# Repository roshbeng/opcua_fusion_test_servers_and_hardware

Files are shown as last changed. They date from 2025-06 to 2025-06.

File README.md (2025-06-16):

# OPC UA Controlled Cobot and Conveyor System

This project features a 3D-printable 6-axis collaborative robot (Cobot) and a conveyor belt system, both designed to be controlled remotely via OPC UA servers running on Raspberry Pi. The system is a complete mechatronics project, including 3D CAD models, electronic circuit diagrams, and Python control scripts.

> **Note:** This project is designed to be tested with the OPC UA Fusion application available at [roshbeng/opcua_fusion](https://github.com/roshbeng/opcua_fusion.git). This client provides a user interface to connect to the servers and execute the defined methods.

## Features

*   **Remote Control:** Utilizes the OPC UA protocol for robust and standardized industrial communication.
*   **Raspberry Pi Based:** The control logic runs on Raspberry Pi, leveraging its GPIO capabilities to drive servo motors.
*   **Complete Design Files:** Includes comprehensive CAD models in various formats (`.f3d`, `.step`, `.ipt`, `.pdf`) for both the cobot and the conveyor.
*   **Asynchronous Operation:** Built with Python's `asyncio` and the `asyncua` library for efficient, non-blocking server operation.
*   **Hardware Control:** Directly interfaces with servo motors for physical movement and includes a physical shutdown button for safety.
*   **Modular:** The cobot and conveyor operate as separate, independent systems, each with its own OPC UA server.

## Project Structure

```
.
├── requirements.txt
├── CAD models
│   ├── cobot_model
│   │   ├── cobot individual components in step format
│   │   └── cobot_model_v1_inventor
│   └── conveyor_model
│       ├── conveyor individual components in step format
│       └── conveyor_model_v1
├── opcuaprojectcobot
│   ├── cobot_model_3d_cad_design.png
│   ├── the_electronic_circuit_of_the_cobot_model.PNG
│   ├── opcua_cobot_server.py
│   ├── initialze.py
│   ├── robo_arm_without_opc.py
│   └── shutdownbutton.py
└── opcuaprojectconveyor
    ├── conveyor_model_3d_cad_design.png
    ├── the_electronic_circuit_of_the_conveyor_model.PNG
    ├── opcua_conveyor_server.py
    └── shutdownbutton.py
```

## 1. Collaborative Robot (Cobot)

The cobot is a 6-axis robotic arm designed for pick-and-place operations. It is controlled by five servo motors for its joints and one for the gripper.

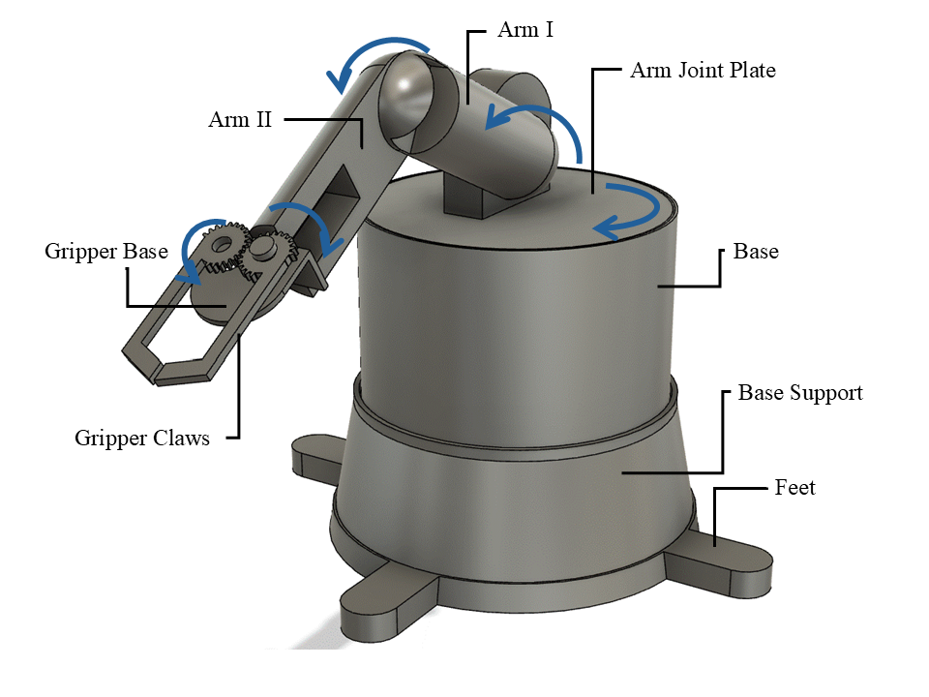
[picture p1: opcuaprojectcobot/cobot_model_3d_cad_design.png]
Cobot 3D Model


### Cobot Electronics

The cobot is controlled by a Raspberry Pi connected to six servo motors and a physical shutdown button.

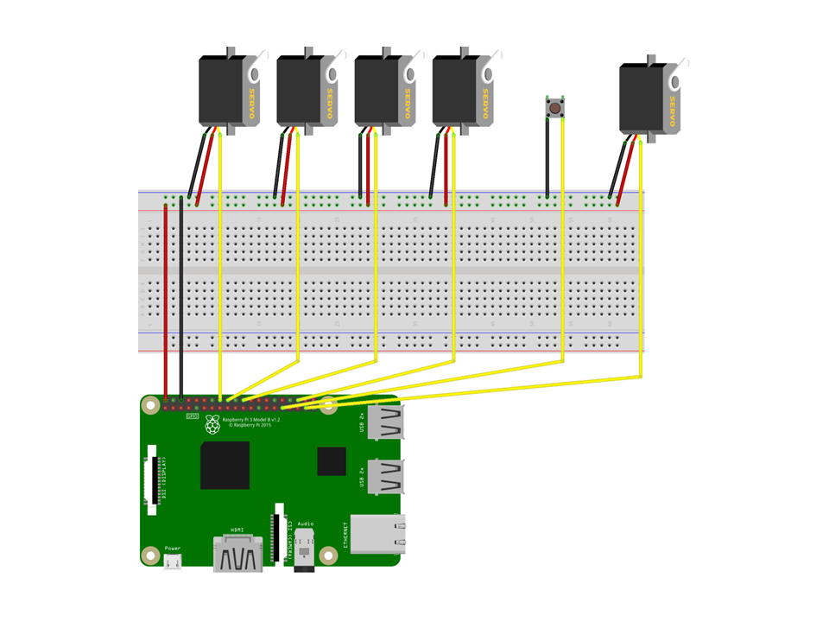
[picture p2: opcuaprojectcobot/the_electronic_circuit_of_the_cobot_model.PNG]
Cobot Circuit Diagram


### Cobot OPC UA Server (`opcua_cobot_server.py`)

This script creates an OPC UA server on a Raspberry Pi to expose control methods for the cobot.

*   **Endpoint:** `opc.tcp://192.168.1.3:4840/cobot_arm`
*   **GPIO Pins Used:**
    *   Servos: `16`, `25`, `23`, `24`, `26`
    *   Shutdown Button: `6`
*   **OPC UA Methods:**
    *   `move_arm(command_bool)`: Executes a pre-programmed sequence of movements. Returns `True` on completion.
    *   `reference_cobot()`: Moves the cobot to a home/reference position. Returns `True`.
    *   `stop_cobot()`: Stops all servos and initiates a system shutdown of the Raspberry Pi.
*   **OPC UA Variables & Properties:**
    *   `claw_position`: A variable to hold the gripper's position (not fully implemented in the provided script).
    *   `server_timestamp`: A variable that updates every second with the current server time.
    *   `Manufacturer`: "HomeBuiltCobot"
    *   `Version`: "1.0"

## 2. Conveyor System

A simple conveyor system designed to transport parts. It is driven by a single continuous rotation servo motor.

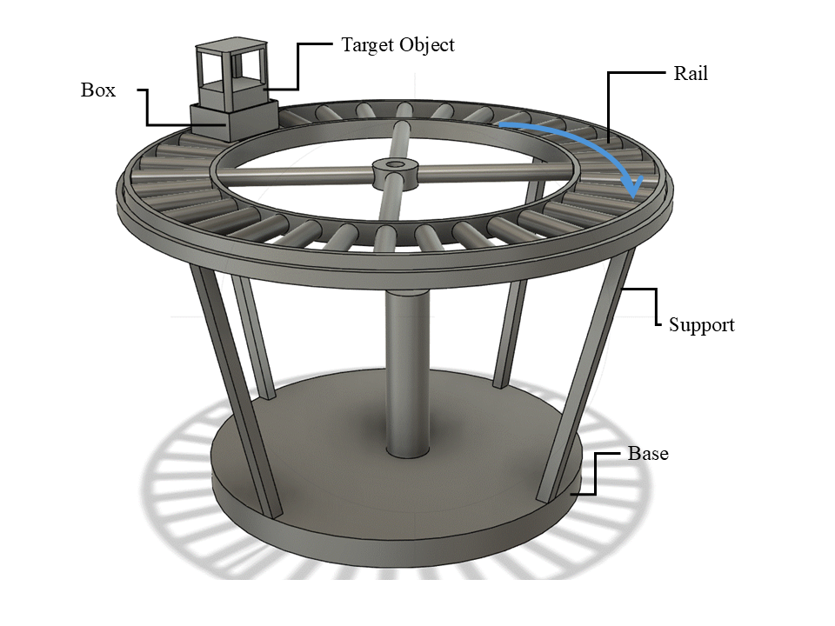
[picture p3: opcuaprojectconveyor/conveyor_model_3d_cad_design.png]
Conveyor 3D Model


### Conveyor Electronics

The conveyor is controlled by a separate Raspberry Pi, connected to one servo and a shutdown button.

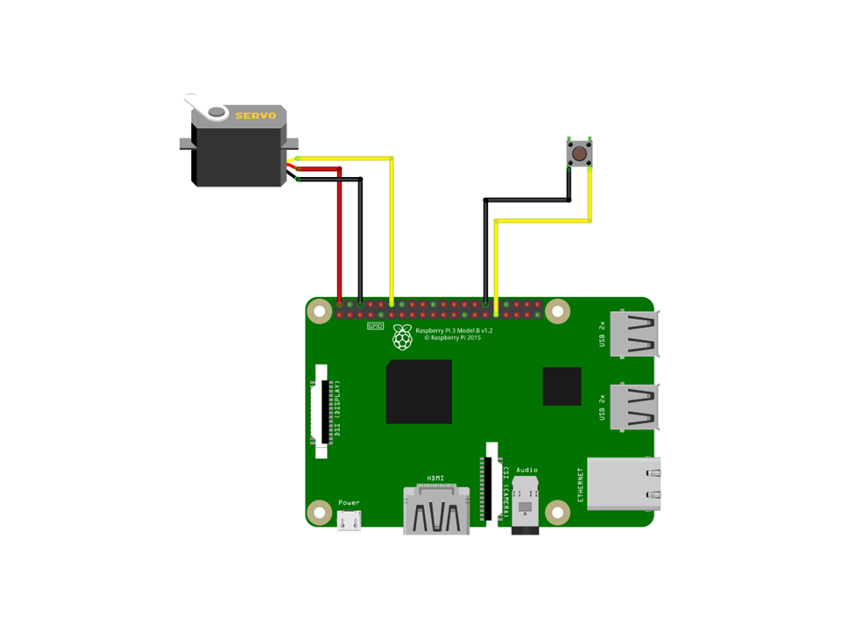
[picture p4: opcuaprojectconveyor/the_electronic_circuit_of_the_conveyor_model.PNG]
Conveyor Circuit Diagram


### Conveyor OPC UA Server (`opcua_conveyor_server.py`)

This script creates an OPC UA server to control the conveyor motor.

*   **Endpoint:** `opc.tcp://192.168.1.2:4840/conveyor`
*   **GPIO Pins Used:**
    *   Servo: `18`
    *   Shutdown Button: `6`
*   **OPC UA Methods:**
    *   `initialize()`: Moves the conveyor to an initial/home position. Returns `True`.
    *   `move_and_supply()`: Runs the conveyor motor to transport items. Returns `True`.
*   **OPC UA Variables & Properties:**
    *   `server_timestamp`: A variable that updates every second with the current server time.
    *   `Manufacturer`: "HomeBuiltConveyor"
    *   `Version`: "1.0"

## 3. CAD Models

The `CAD models` directory contains all the source files for 3D printing and assembly.
*   **Fusion 360 (`.f3d`):** The primary source files for the assemblies.
*   **STEP (`.step`):** A neutral format for use in any CAD software. Individual components are also provided in this format.
*   **Inventor (`.ipt`, `.iam`):** Native files for Autodesk Inventor.
*   **PDF (`.pdf`):** 2D technical drawings of the components.

## Getting Started

### Prerequisites

*   **Hardware:**
    *   2 x Raspberry Pi (3B+ or newer recommended)
    *   ~6 x Servo Motors (e.g., MG996R or similar)
    *   2 x Push Buttons
    *   Breadboards, jumper wires, and an appropriate power supply for the servos.
    *   Ethernet cables and a network switch for direct connection (optional but recommended).
*   **Software:**
    *   Python 3.7+
    *   Git

### Installation & Setup

1.  **Clone the repository:**
    ```bash
    git clone https://github.com/roshbeng/opcua_fusion_test_servers_and_hardware.git
    cd opcua_fusion_test_servers_and_hardware
    ```

2.  **Install Python dependencies:**
    ```bash
    pip install -r requirements.txt
    ```
    Note: `RPi.GPIO` can only be installed and used on a Raspberry Pi.

3.  **Hardware Wiring:**
    *   **For the Cobot Pi:** Connect the servo signal wires to GPIO pins 16, 25, 23, 24, 26. Connect the shutdown button to GPIO 6.
    *   **For the Conveyor Pi:** Connect the servo signal wire to GPIO pin 18. Connect the shutdown button to GPIO 6.
    *   Ensure all servos and the Raspberry Pis have a common ground (GND). Power the servos with a separate, adequate power supply.

4.  **Network Configuration:**
    The scripts use hardcoded IP addresses: `192.168.1.3` for the cobot and `192.168.1.2` for the conveyor. You must either:
    *   **Option A (Recommended):** Set up a direct Ethernet connection to your laptop by creating a network bridge. See the section below.
    *   **Option B:** Assign these static IPs to your Raspberry Pis on your existing network.
    *   **Option C:** Modify the `endpoint` URL in each server script (`opcua_cobot_server.py` and `opcua_conveyor_server.py`) to match the actual IP addresses of your devices.

### 🔌 Connecting Hardware Directly via Ethernet (Network Bridge)

To connect the Raspberry Pi-based hardware directly to the laptop running the client application without an external router, you can create a network bridge.

#### Network Topology

```
(Internet) --- Wi-Fi ---> [ Laptop (Running Client) ] --- Ethernet ---> [ Switch ] --- Ethernet ---> [ Pi 1: Conveyor (192.168.1.2) ]
                                                                             |
                                                                              --- Ethernet ---> [ Pi 2: Cobot (192.168.1.3) ]
```

#### Laptop Setup Guide

Your laptop must have a static IP address on the same network as the hardware. We will use the `192.168.1.x` subnet.

**On Windows:**

1.  Open Network Connections: Press `Win + R`, type `ncpa.cpl`, and press Enter.
2.  **Set Static IP on Ethernet Port**: Right-click your **Ethernet** adapter > **Properties** > **Internet Protocol Version 4 (TCP/IPv4)** > **Properties**. Select "Use the following IP address" and enter:
    -   IP address: `192.168.1.1`
    -   Subnet mask: `255.255.255.0`
3.  **Share Wi-Fi Connection**: Right-click your **Wi-Fi** adapter > **Properties** > **Sharing** tab. Check the box "Allow other network users to connect..." and select your **Ethernet** adapter from the dropdown.

**On macOS:**

1.  Open **System Settings** > **Network**.
2.  **Set Static IP on Ethernet Port**: Select your **Ethernet** adapter > **Details...** > **TCP/IP**. Set "Configure IPv4" to **Manually** and enter:
    -   IP Address: `192.168.1.1`
    -   Subnet Mask: `255.255.255.0`
3.  **Share Wi-Fi Connection**: Go to **System Settings** > **General** > **Sharing**. Turn on **Internet Sharing**. Configure it to share from **Wi-Fi** to computers using your **Ethernet** adapter.

### Running the Servers

1.  **On the Cobot Raspberry Pi**, run:
    ```bash
    python opcuaprojectcobot/opcua_cobot_server.py
    ```

2.  **On the Conveyor Raspberry Pi**, run:
    ```bash
    python opcuaprojectconveyor/opcua_conveyor_server.py
    ```

You should see a message indicating that the OPC UA server has started on each device.

### Interacting with the System

Use an OPC UA client to connect to the servers and control the hardware. The [opcua_fusion](https://github.com/roshbeng/opcua_fusion.git) project is recommended.

1.  Start the client application on your laptop.
2.  Connect to the Cobot server endpoint: `opc.tcp://192.168.1.3:4840/cobot_arm`
3.  Connect to the Conveyor server endpoint: `opc.tcp://192.168.1.2:4840/conveyor`
4.  Once connected, you can browse the OPC UA objects and call the methods (e.g., `move_arm`, `initialize`) to operate the system.

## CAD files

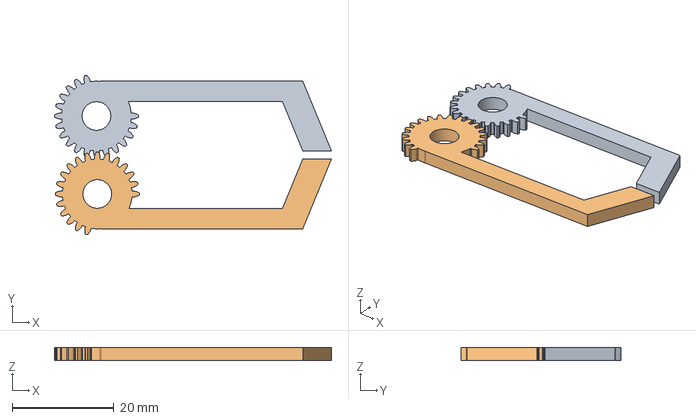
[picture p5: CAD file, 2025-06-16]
CAD models/cobot_model/cobot individual components in step format/GRIPPER CLAW v2.step
54.5 x 31.4 x 2.64 mm

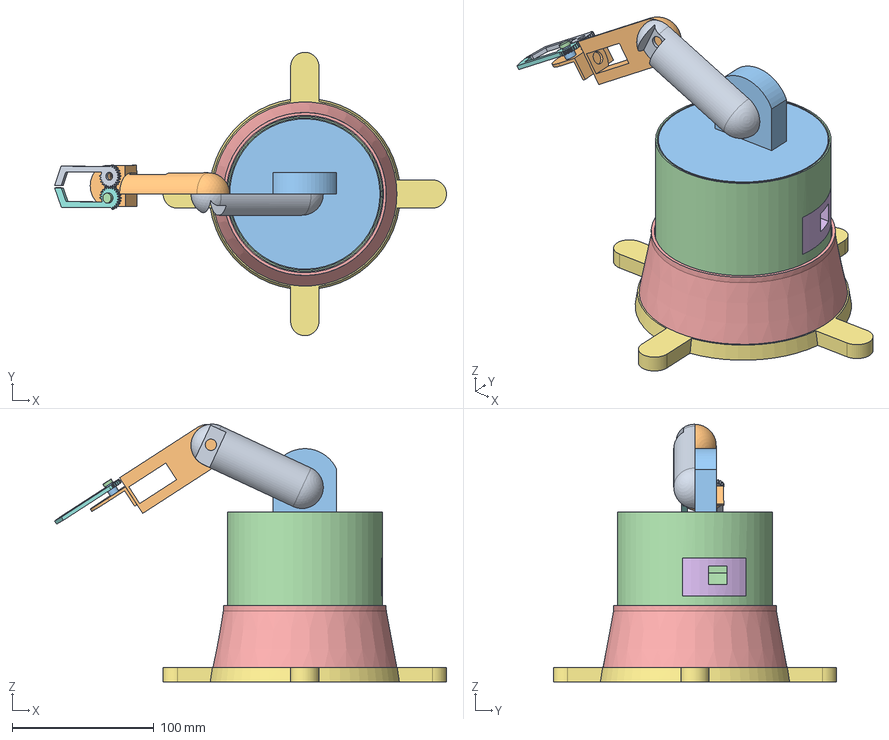
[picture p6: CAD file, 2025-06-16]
CAD models/cobot_model/cobot_model_v1.step
276.7 x 200.0 x 181.9 mm
arm1
arm2
shoulder
base1 (1)
base2
base1
base_support
gripper_assembly

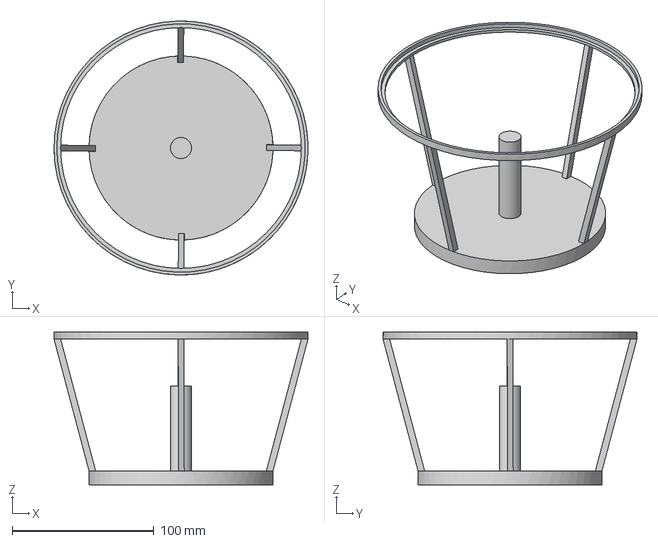
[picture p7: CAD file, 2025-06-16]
CAD models/conveyor_model/conveyor individual components in step format/base_and_support v3.step
179.4 x 179.4 x 108.0 mm

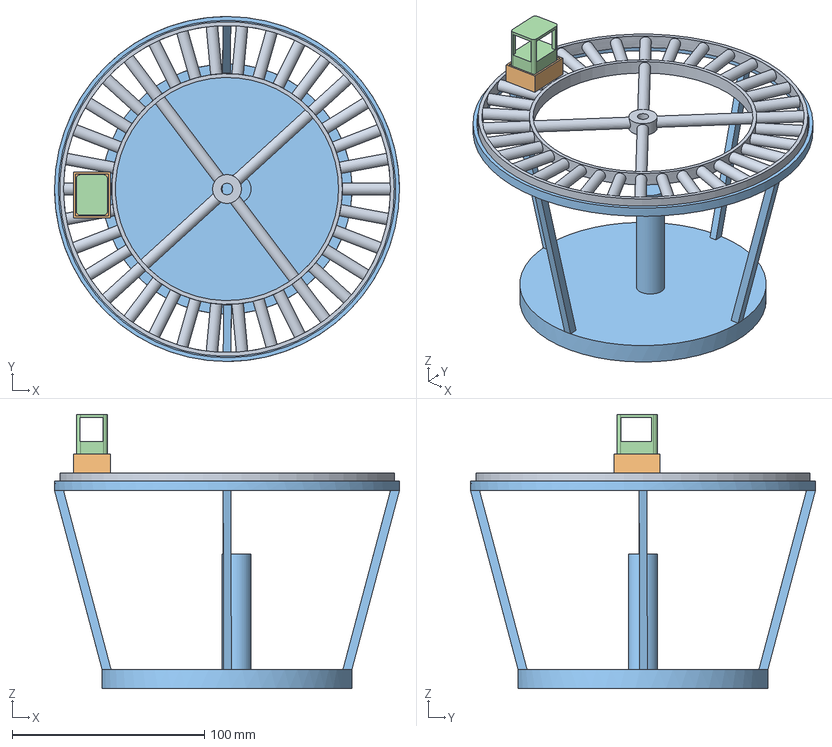
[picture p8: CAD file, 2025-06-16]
CAD models/conveyor_model/conveyor_model_v1.step
179.4 x 179.4 x 142.5 mm
rail
support

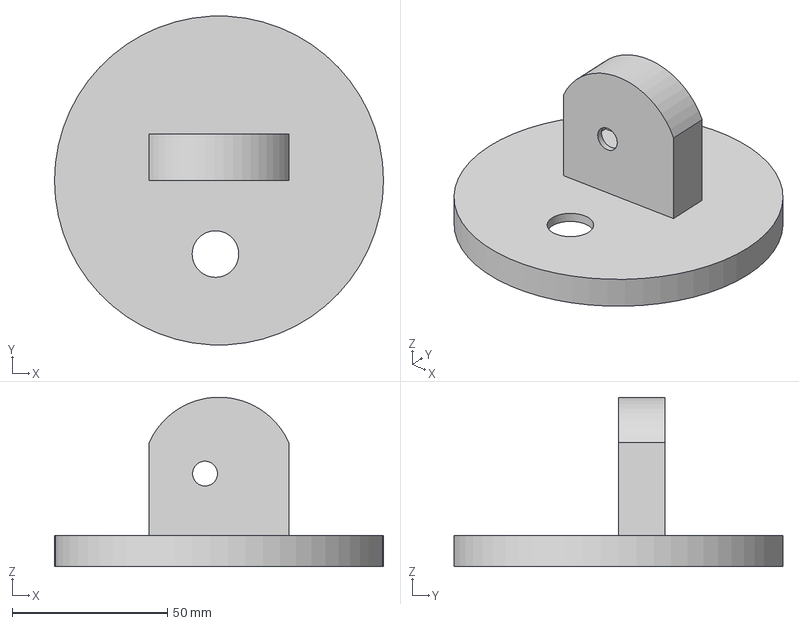
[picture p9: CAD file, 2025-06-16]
CAD models/cobot_model/cobot individual components in step format/ARM JOINT PLATE v3.step
106.0 x 105.8 x 54.6 mm

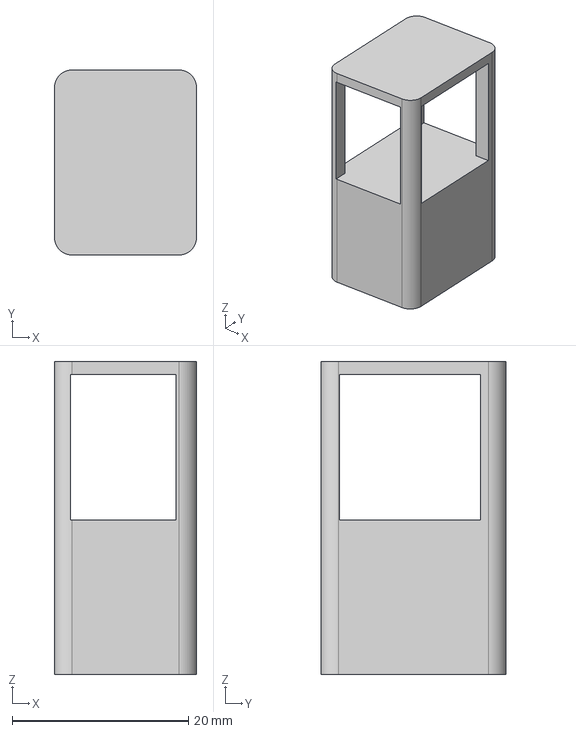
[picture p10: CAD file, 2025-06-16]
CAD models/conveyor_model/conveyor individual components in step format/pick v2.step
16.1 x 21.0 x 35.5 mm

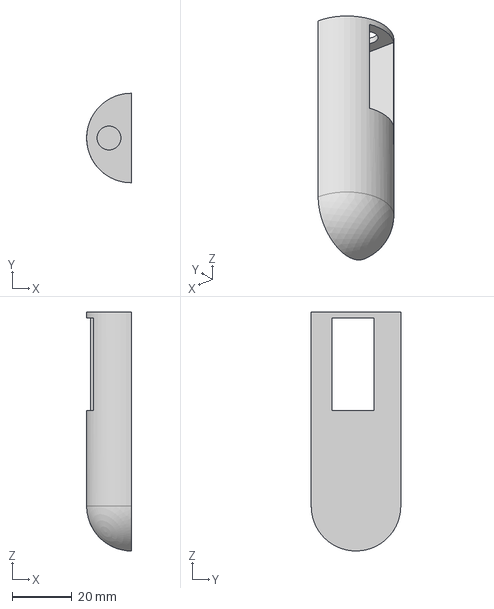
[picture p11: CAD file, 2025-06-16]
CAD models/cobot_model/cobot individual components in step format/ARM II v7.step
15.0 x 30.0 x 80.0 mm

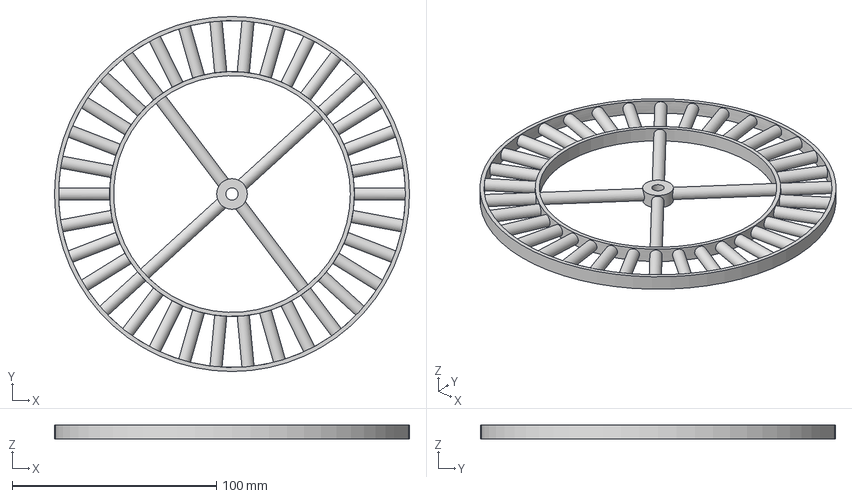
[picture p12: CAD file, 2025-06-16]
CAD models/conveyor_model/conveyor individual components in step format/rail v2.step
174.0 x 174.0 x 7.00 mm

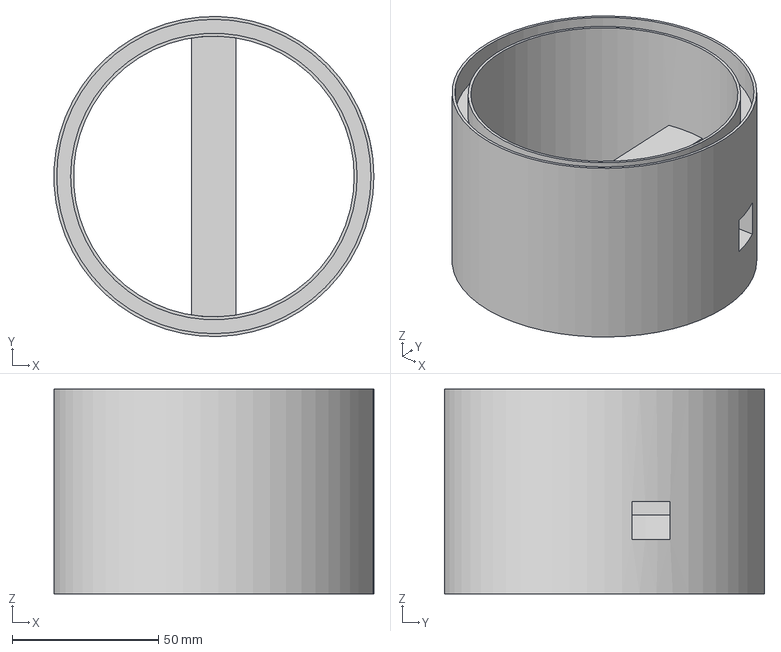
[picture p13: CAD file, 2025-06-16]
CAD models/cobot_model/cobot individual components in step format/BASE v4.step
109.4 x 109.5 x 70.0 mm
base1 (1)
base1

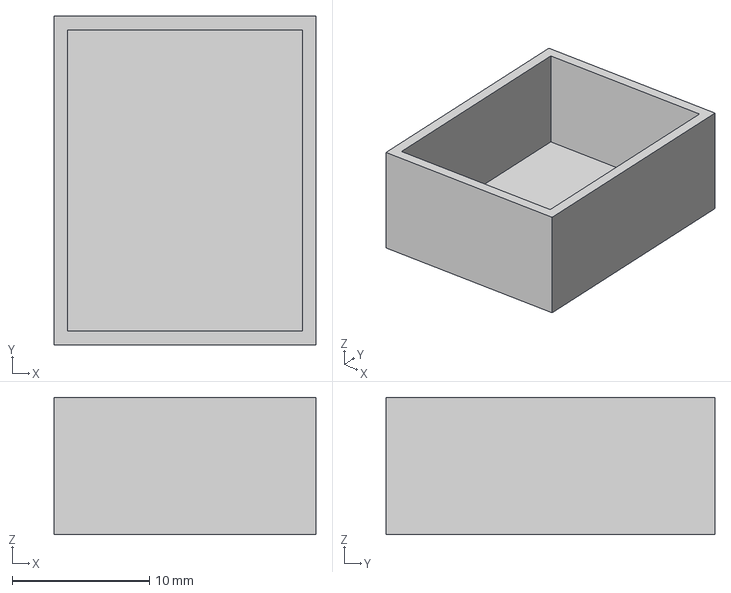
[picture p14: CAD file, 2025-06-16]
CAD models/conveyor_model/conveyor individual components in step format/box v2.step
19.1 x 24.0 x 10.0 mm

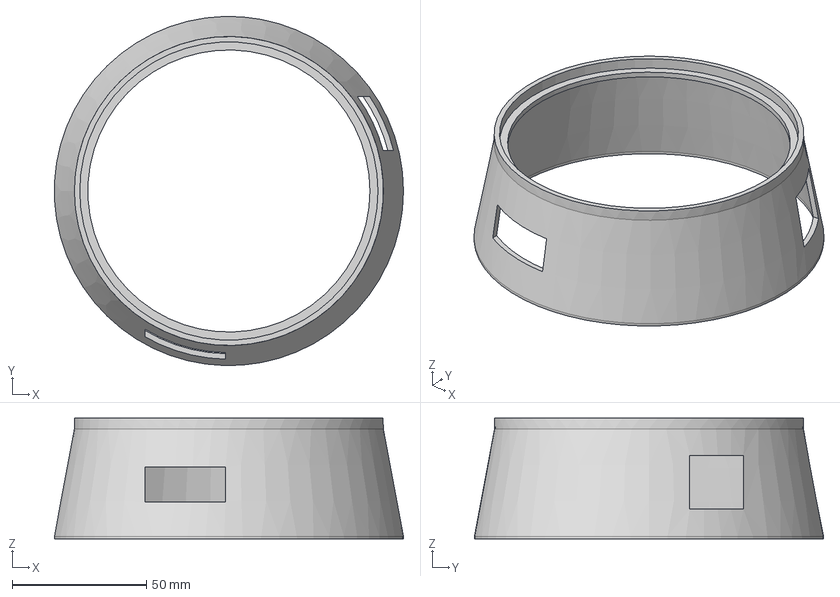
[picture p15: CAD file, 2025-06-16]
CAD models/cobot_model/cobot individual components in step format/BASE SUPPORT v8.step
129.9 x 130.0 x 45.0 mm

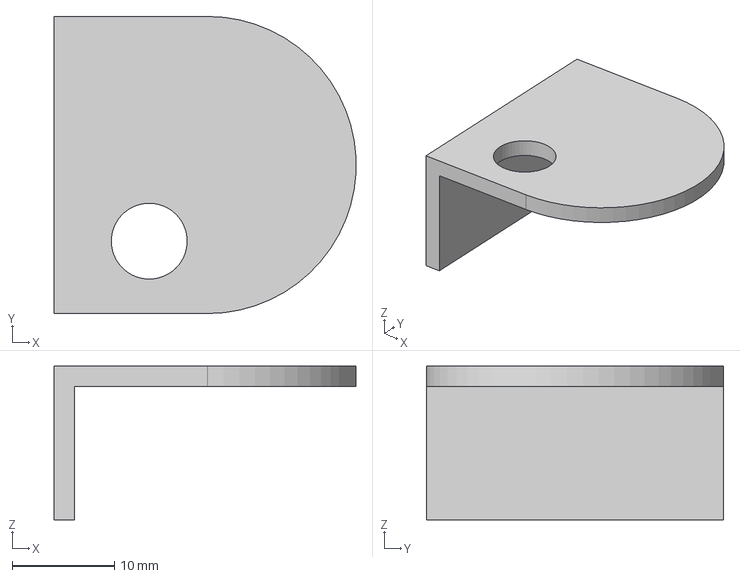
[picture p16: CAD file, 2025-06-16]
CAD models/cobot_model/cobot individual components in step format/GRIPPER BASE v2.step
29.5 x 29.0 x 15.0 mm

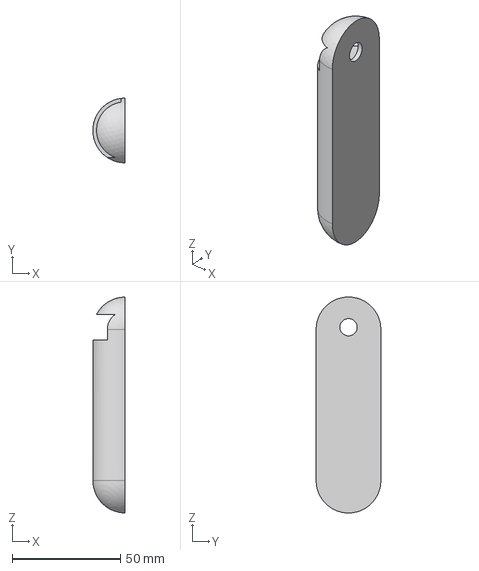
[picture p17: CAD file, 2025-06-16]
CAD models/cobot_model/cobot individual components in step format/ARM I v5.step
15.0 x 30.0 x 100.0 mm

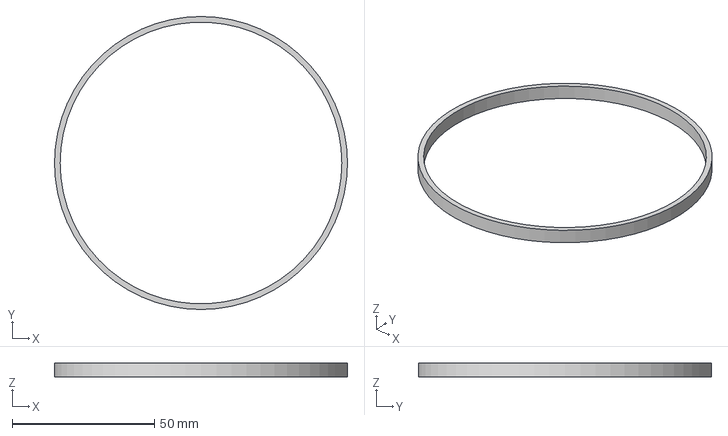
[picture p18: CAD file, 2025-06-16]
CAD models/cobot_model/cobot individual components in step format/ring v3.step
103.0 x 103.0 x 5.00 mm

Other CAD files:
CAD models/cobot_model/cobot individual components in step format/GRIPPER SUPPORTS I, II & III v5.step
CAD models/cobot_model/cobot individual components in step format/COBOT'S FOOT.step
CAD models/cobot_model/cobot_model_v1_inventor/Part16.ipt
CAD models/cobot_model/cobot_model_v1_inventor/arm1.ipt
CAD models/cobot_model/cobot_model_v1_inventor/arm2.ipt
CAD models/cobot_model/cobot_model_v1_inventor/base1 (1).ipt
CAD models/cobot_model/cobot_model_v1_inventor/base1.ipt
CAD models/cobot_model/cobot_model_v1_inventor/base2.ipt
CAD models/cobot_model/cobot_model_v1_inventor/base_support.ipt
CAD models/cobot_model/cobot_model_v1_inventor/gripper_assembly.iam
CAD models/cobot_model/cobot_model_v1_inventor/robotic_arm.iam
CAD models/cobot_model/cobot_model_v1_inventor/shoulder.ipt
CAD models/conveyor_model/conveyor_model_v1.f3d
CAD models/conveyor_model/conveyor_model_v1/box.ipt
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

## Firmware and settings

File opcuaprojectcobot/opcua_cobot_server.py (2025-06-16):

import asyncio
from asyncua import ua, uamethod, Server
from datetime import datetime, timezone
import re, sys, os
import RPi.GPIO as GPIO
from time import sleep

pwm_objects = {}

def get_or_create_pwm(pin, frequency=50):
    if pin not in pwm_objects:
        GPIO.setup(pin, GPIO.OUT)
        new_pwm = GPIO.PWM(pin, frequency)
        new_pwm.start(0)
        pwm_objects[pin] = new_pwm 
    return pwm_objects[pin]


def stop_all_servos():
    for pwm_obj in pwm_objects.values():
        pwm_obj.stop()
    pwm_objects.clear()


def cleanup_gpio():
    GPIO.cleanup()
    print("GPIO cleanup completed.")

BUTTON_PIN = 6

async def monitor_button():

    while True:
        button_state = GPIO.input(BUTTON_PIN)
        if button_state == 0:
            print("Physical button pressed - shutting down system...")
            stop_all_servos()
            cleanup_gpio()
            os.system("sudo shutdown -h now")
        await asyncio.sleep(0.1)


@uamethod
async def move_arm(parent, command_bool):
    try:
        GPIO.setmode(GPIO.BCM)

        pwm16 = get_or_create_pwm(16)
        pwm25 = get_or_create_pwm(25)
        pwm23 = get_or_create_pwm(23)
        pwm24 = get_or_create_pwm(24)
        pwm26 = get_or_create_pwm(26)

        if command_bool:
            print("Moving arm...")
            pwm25.ChangeDutyCycle(8.5)
            await asyncio.sleep(1)
            pwm26.ChangeDutyCycle(12.5)
            await asyncio.sleep(1)
            pwm23.ChangeDutyCycle(3.5)
            await asyncio.sleep(1)
            pwm23.ChangeDutyCycle(6)
            await asyncio.sleep(1)
            pwm16.ChangeDutyCycle(12.5)
            await asyncio.sleep(1)
            pwm24.ChangeDutyCycle(12.5)
            await asyncio.sleep(1)
            pwm23.ChangeDutyCycle(4)
            await asyncio.sleep(1)
            pwm26.ChangeDutyCycle(10)
            await asyncio.sleep(1)
            pwm25.ChangeDutyCycle(10.5)
            await asyncio.sleep(1)
            pwm26.ChangeDutyCycle(12.5)
            await asyncio.sleep(1)
            pwm23.ChangeDutyCycle(6)
            await asyncio.sleep(1)
            pwm25.ChangeDutyCycle(9)
            await asyncio.sleep(1)
            pwm16.ChangeDutyCycle(3.5)
            await asyncio.sleep(1)
            pwm25.ChangeDutyCycle(11)
            await asyncio.sleep(1)
            pwm23.ChangeDutyCycle(4)
            await asyncio.sleep(1)
            pwm26.ChangeDutyCycle(10)
            await asyncio.sleep(1)
            pwm25.ChangeDutyCycle(9.5)
            await asyncio.sleep(1)
            pwm26.ChangeDutyCycle(12.5)
            await asyncio.sleep(1)
            pwm23.ChangeDutyCycle(3.5)
            await asyncio.sleep(1)
            print("Arm movement completed.")

            print("Going to home position...")
            pwm16.ChangeDutyCycle(7)
            await asyncio.sleep(1)
            pwm25.ChangeDutyCycle(8)
            await asyncio.sleep(1)
            pwm26.ChangeDutyCycle(10)
            await asyncio.sleep(1)
            pwm23.ChangeDutyCycle(3.5)
            await asyncio.sleep(1)
            pwm24.ChangeDutyCycle(12.5)
            await asyncio.sleep(1)
            pwm26.ChangeDutyCycle(12.5)
            await asyncio.sleep(1)
            stop_all_servos()
        else:
            print("Stopping arm movement...")

    except Exception as e:
        print(f"Error during arm movement: {e}")
        cleanup_gpio()

    return True

@uamethod
async def reference_cobot(parent):
    try:
        print("Referencing Cobot...")
        pwm16 = get_or_create_pwm(16)
        pwm25 = get_or_create_pwm(25)
        pwm23 = get_or_create_pwm(23)
        pwm24 = get_or_create_pwm(24)
        pwm26 = get_or_create_pwm(26)

        pwm16.ChangeDutyCycle(7)
        await asyncio.sleep(1)
        pwm25.ChangeDutyCycle(8)
        await asyncio.sleep(1)
        pwm26.ChangeDutyCycle(10)
        await asyncio.sleep(1)
        pwm23.ChangeDutyCycle(3.5)
        await asyncio.sleep(1)
        pwm24.ChangeDutyCycle(12.5)
        await asyncio.sleep(1)
        pwm26.ChangeDutyCycle(12.5)
        await asyncio.sleep(1)

        print("Cobot referenced successfully.")
        stop_all_servos()

    except Exception as e:
        print(f"Error during referencing: {e}")
        cleanup_gpio()

    return True

@uamethod
async def stop_cobot(parent):
    print("Cobot stopping, and shutting down the system...")
    await asyncio.sleep(3)
    stop_all_servos()
    cleanup_gpio()
    os.system("sudo shutdown -h now")
    return True


async def generate_opc_model(server, namespace_id):
    cobot_interface = await server.nodes.objects.add_object(namespace_id, "cobot interface")

    claw_position = await cobot_interface.add_variable(namespace_id, "claw position", 0.0)
    server_timestamp = await cobot_interface.add_variable(namespace_id, "server timestamp", datetime.now(timezone.utc))

    await cobot_interface.add_property(namespace_id, "Manufacturer", "HomeBuiltCobot")
    await cobot_interface.add_property(namespace_id, "Version", "1.0")

    move_functions_channel = await cobot_interface.add_object(namespace_id, "move functions channel")

    move_arm_arg = ua.Argument()
    move_arm_arg.Name = "Command"
    move_arm_arg.DataType = ua.NodeId(ua.ObjectIds.Boolean)

    method_true_output = ua.Argument()
    method_true_output.Name = "Execution Result"
    method_true_output.DataType = ua.NodeId(ua.ObjectIds.Boolean)

    await move_functions_channel.add_method(namespace_id, "move_arm", move_arm, [move_arm_arg], [method_true_output])
    await cobot_interface.add_method(namespace_id, "reference_cobot", reference_cobot, [], [method_true_output])
    await cobot_interface.add_method(namespace_id, "stop_cobot", stop_cobot, [], [method_true_output])

    return server_timestamp


async def start_server(endpoint="opc.tcp://192.168.1.3:4840/cobot_arm"):

    server = Server()
    await server.init()
    server.set_endpoint(endpoint)


    if match := re.search(r"^opc\\.tcp://(.*)/(.*)$", endpoint):
        uri = match.group(2)
    else:
        uri = "cobot_arm"

    namespace_id = await server.register_namespace(uri)
    server_timestamp = await generate_opc_model(server, namespace_id)

    GPIO.setmode(GPIO.BCM)
    GPIO.setup(BUTTON_PIN, GPIO.IN, pull_up_down=GPIO.PUD_UP)

    async with server:
        print(f"OPC UA Server started at {endpoint}")

        asyncio.create_task(monitor_button())

        while True:
            await server_timestamp.write_value(datetime.now(timezone.utc))
            await asyncio.sleep(1)


if __name__ == "__main__":
    try:
        GPIO.setmode(GPIO.BCM)
        asyncio.run(start_server())
    except (KeyboardInterrupt, SystemExit):
        cleanup_gpio()
        sys.exit(0)

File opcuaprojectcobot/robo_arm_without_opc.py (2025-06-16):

import RPi.GPIO as GPIO
from time import sleep
                                                              
GPIO.setmode(GPIO.BCM)
pwmPin16 = 16
GPIO.setup(pwmPin16, GPIO.OUT)
pwm16=GPIO.PWM(pwmPin16,50)
pwm16.start(0)

pwmPin25 = 25
GPIO.setup(pwmPin25, GPIO.OUT)
pwm25=GPIO.PWM(pwmPin25,50)
pwm25.start(0)

pwmPin23 = 23
GPIO.setup(pwmPin23, GPIO.OUT)
pwm23=GPIO.PWM(pwmPin23,50)
pwm23.start(0)

pwmPin24 = 24
GPIO.setup(pwmPin24, GPIO.OUT)
pwm24=GPIO.PWM(pwmPin24,50)
pwm24.start(0)

pwmPin26 = 26
GPIO.setup(pwmPin26, GPIO.OUT)
pwm26=GPIO.PWM(pwmPin26,50)
pwm26.start(0)


try:
    pwm25.ChangeDutyCycle(float(8.5))
    sleep(1)
    pwm26.ChangeDutyCycle(float(12.5))
    sleep(1)
    pwm23.ChangeDutyCycle(float(3.5))
    sleep(1)
    pwm23.ChangeDutyCycle(float(6))
    sleep(1)

    pwm16.ChangeDutyCycle(float(12.5))
    sleep(1)
    pwm24.ChangeDutyCycle(float(12.5))
    sleep(1)
    pwm23.ChangeDutyCycle(float(4))
    sleep(1)
    pwm26.ChangeDutyCycle(float(10))
    sleep(1)
    pwm25.ChangeDutyCycle(float(10.6))
    sleep(1)
    pwm26.ChangeDutyCycle(float(12.5))
    sleep(1)
    pwm23.ChangeDutyCycle(float(6))
    sleep(1)
    pwm25.ChangeDutyCycle(float(9))
    sleep(1)
    pwm16.ChangeDutyCycle(float(3.5))
    sleep(1)
    pwm25.ChangeDutyCycle(float(11))
    sleep(1)
    pwm23.ChangeDutyCycle(float(4))
    sleep(1)
    pwm26.ChangeDutyCycle(float(10))
    sleep(1)
    pwm25.ChangeDutyCycle(float(8.5))
    sleep(1)
    pwm26.ChangeDutyCycle(float(12.5))
    sleep(1)
    pwm23.ChangeDutyCycle(float(3.5))
    sleep(1)


    GPIO.cleanup()
except KeyboardInterrupt:
    GPIO.cleanup()
